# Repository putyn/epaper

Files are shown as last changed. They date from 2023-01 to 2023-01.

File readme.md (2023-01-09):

# epaper 
Adventure with epaper panel to create an epaper wifi connected photoframe.

Project is heavly based on [epdiy project](https://github.com/vroland/epdiy) but with a slightly different hardware, [epaper-breakout](epaper-breakout) is the first iteration of the project which will, hopefully, drive an ED060XC3 panel.

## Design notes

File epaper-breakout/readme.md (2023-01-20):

`Project status: Work in progress`

## ink-frame rev 0.1

Breakout board for [TPS65185](https://www.ti.com/lit/ds/symlink/tps65185.pdf) which supplies the 5 voltages needed to drive e-ink panels, [BQ24075](https://www.ti.com/lit/ds/symlink/bq24075.pdf) 
battery charger and FPC connector for e-ink panel, should fit ED060XC3 panel.

## pcb render
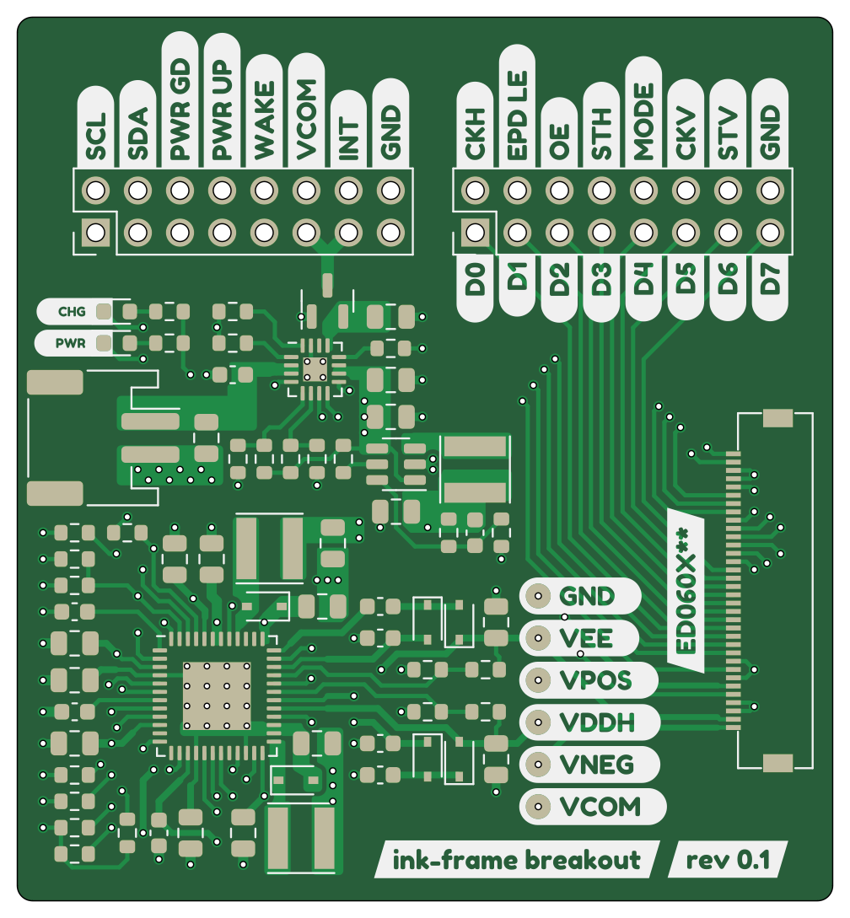
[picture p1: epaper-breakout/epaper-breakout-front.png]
ink-frame front


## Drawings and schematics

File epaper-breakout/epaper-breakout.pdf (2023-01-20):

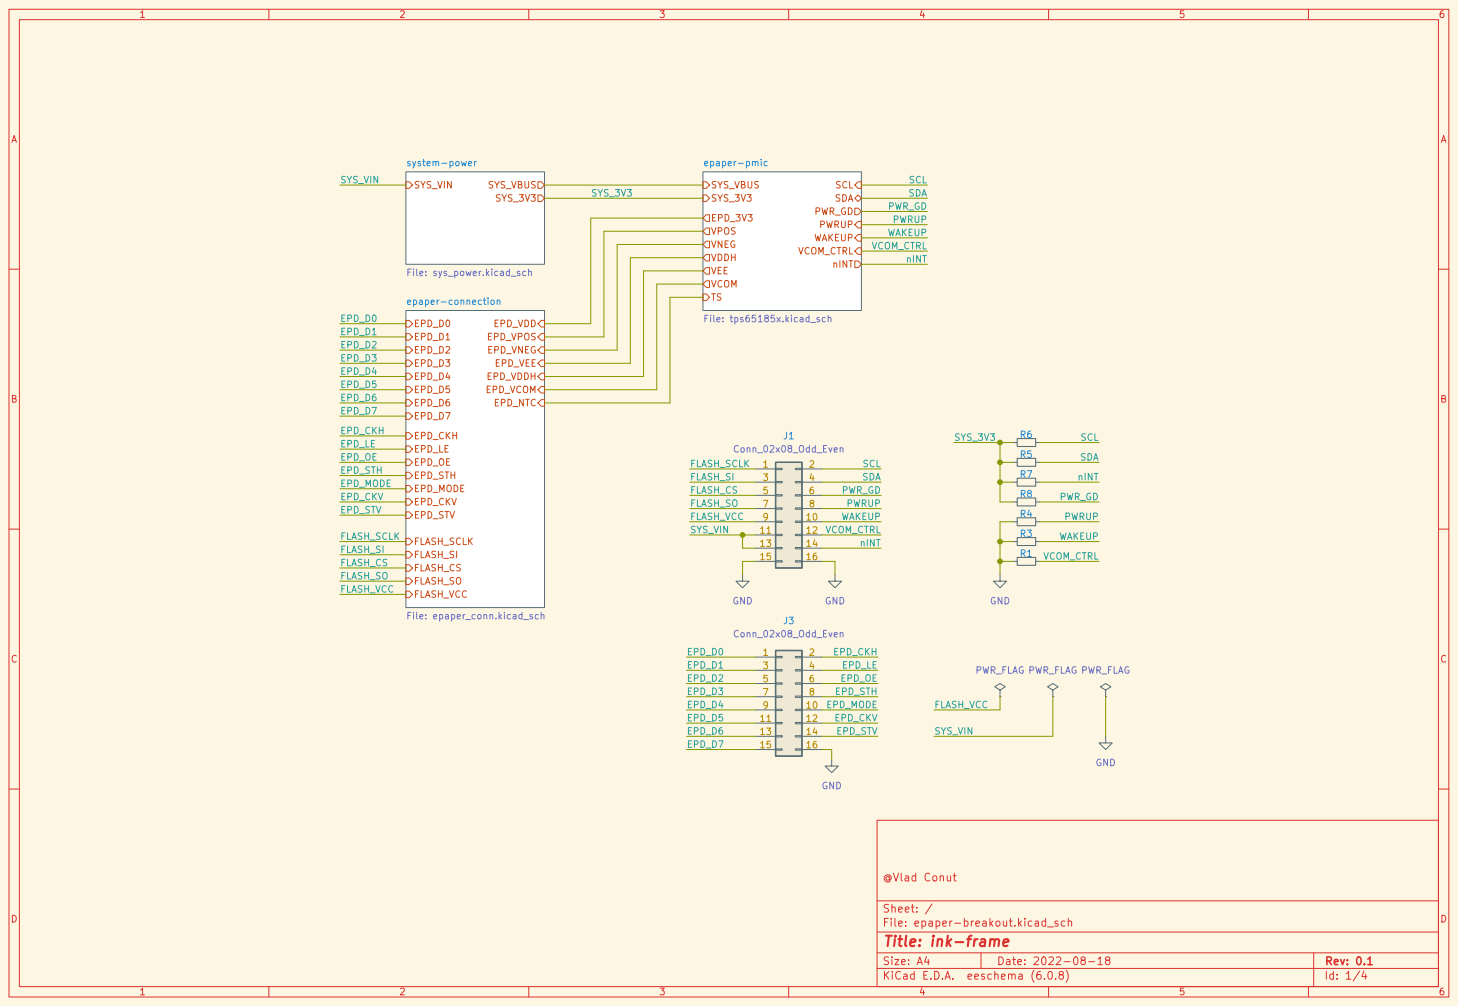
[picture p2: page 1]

File: epaper-breakout.kicad_sch Sheet: / @Vlad Conut

Id: 1/4 Title: ink-frame

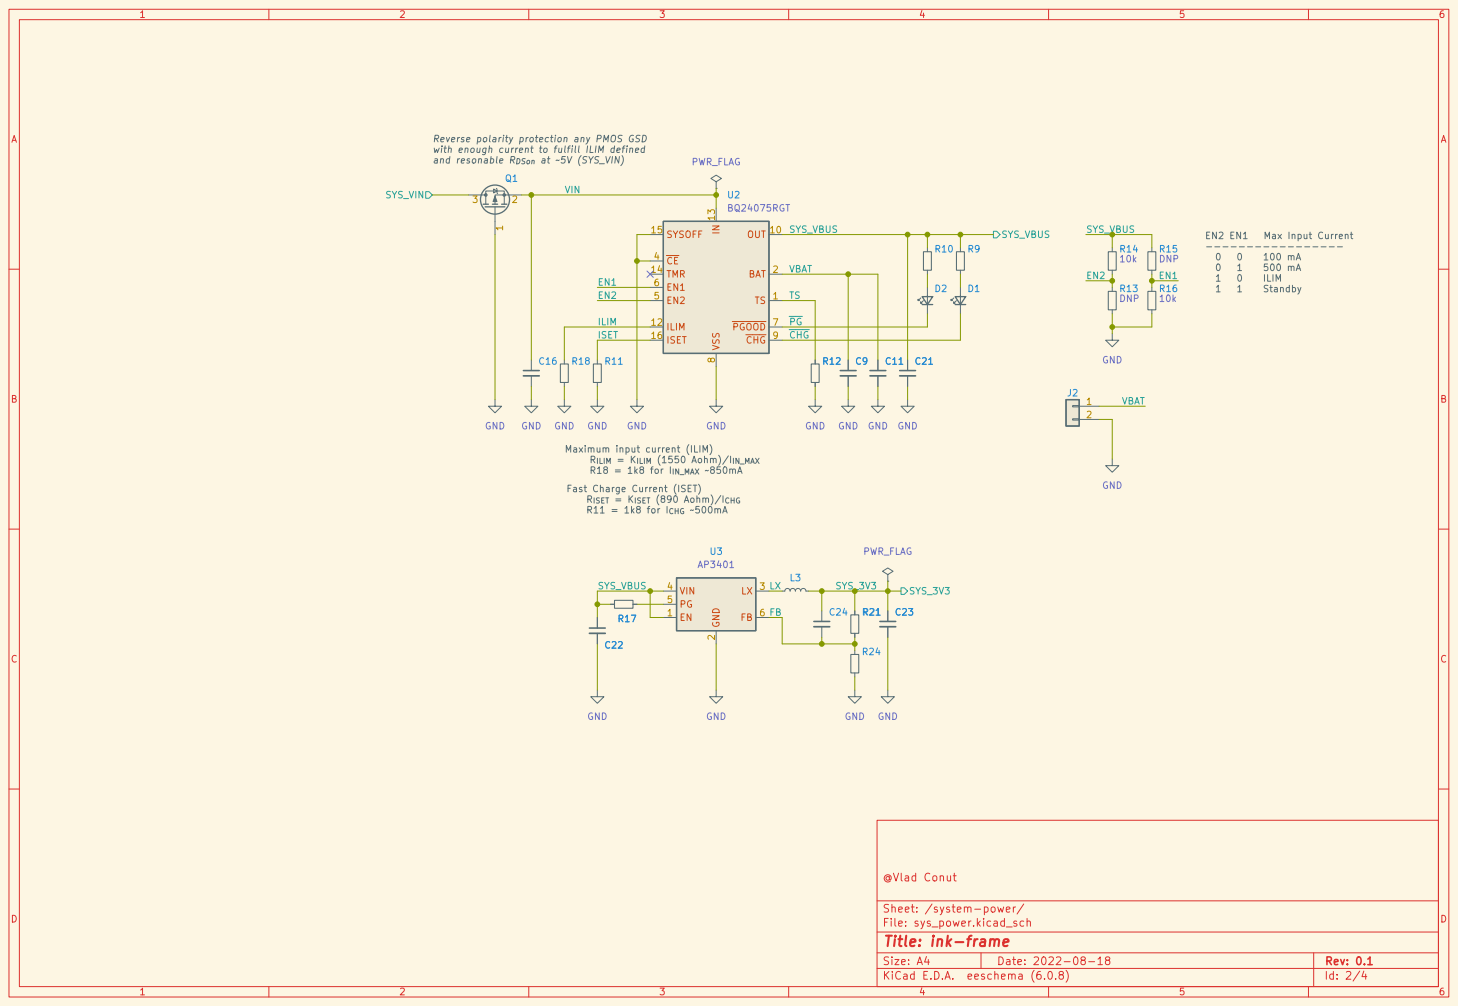
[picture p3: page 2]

Reverse polarity protection any PMOS GSD
with enough current to fulfill ILIM defined

Maximum input current (ILIM)
R_{ILIM} = K_{ILIM} (1550 Aohm)/I_{IN_MAX}
R18 = 1k8 for I_{IN_MAX} ~850mA
Fast Charge Current (ISET)
R_{ISET} = K_{ISET} (890 Aohm)/I_{CHG}
R11 = 1k8 for I_{CHG} ~500mA

Sheet: /system-power/
File: sys_power.kicad_sch
Id: 2/4 Title: ink-frame

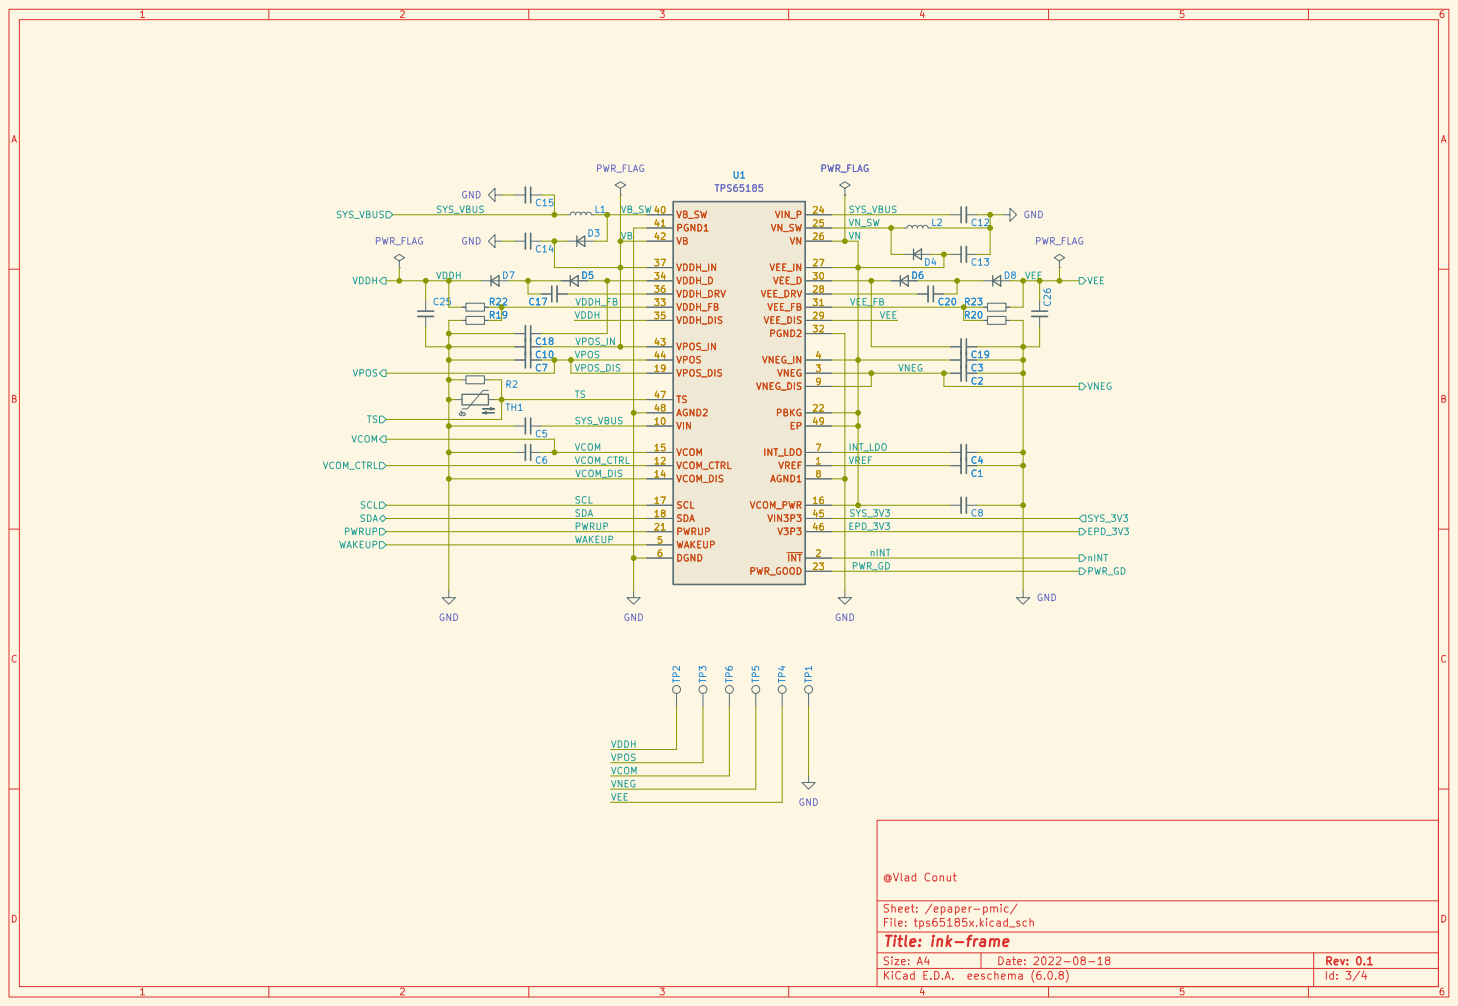
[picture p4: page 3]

VN_SW
VN

Sheet: /epaper-pmic/
File: tps65185x.kicad_sch
Id: 3/4 Title: ink-frame

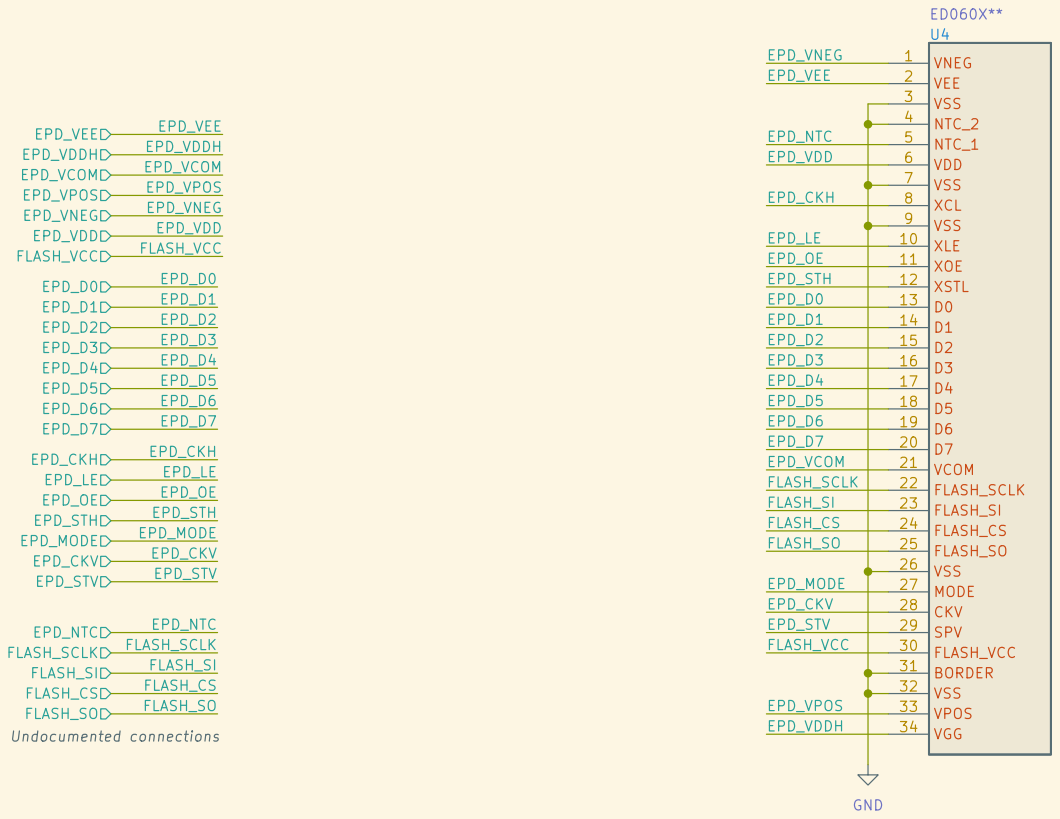
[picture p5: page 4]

Sheet: /epaper-connection/
File: epaper_conn.kicad_sch
Id: 4/4 Title: ink-frame

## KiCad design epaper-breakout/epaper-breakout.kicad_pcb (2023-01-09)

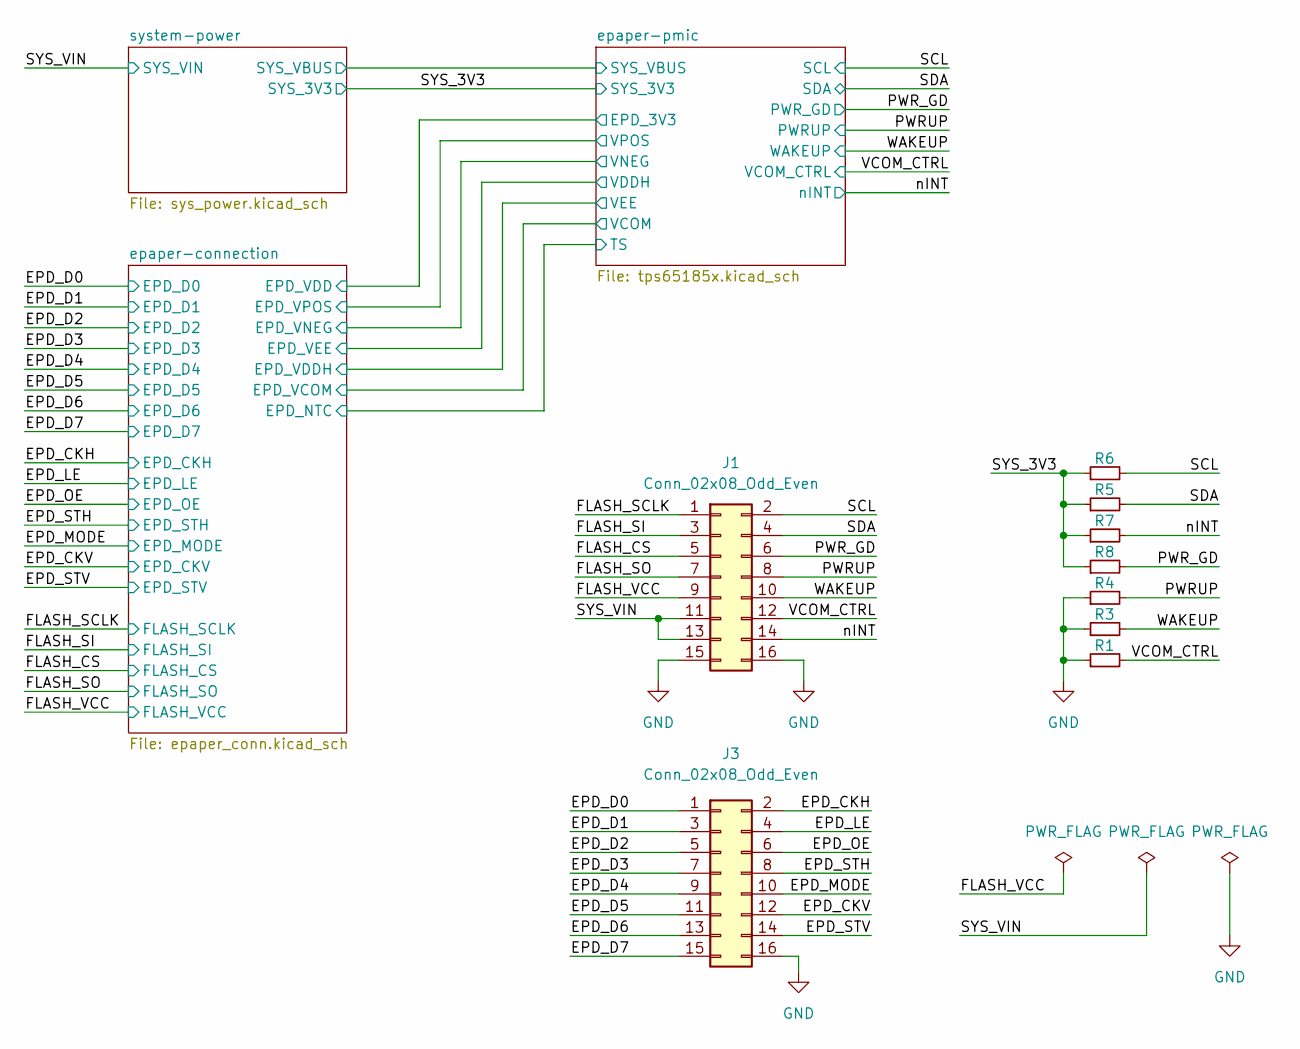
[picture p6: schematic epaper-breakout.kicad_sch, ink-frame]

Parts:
J1, J3: Conn_02x08_Odd_Even; PinHeader_2x08_P2.54mm_Vertical
R1, R3, R4, R7, R8: 100k; R_0603_1608Metric; LCSC C25803
R5, R6: 2k2; R_0603_1608Metric; LCSC C4190

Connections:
/EPD_CKH: J3.2; also elsewhere on the board
/EPD_CKV: J3.12; also elsewhere on the board
/EPD_D0: J3.1; also elsewhere on the board
/EPD_D1: J3.3; also elsewhere on the board
/EPD_D2: J3.5; also elsewhere on the board
/EPD_D3: J3.7; also elsewhere on the board
/EPD_D4: J3.9; also elsewhere on the board
/EPD_D5: J3.11; also elsewhere on the board
/EPD_D6: J3.13; also elsewhere on the board
/EPD_D7: J3.15; also elsewhere on the board
/EPD_LE: J3.4; also elsewhere on the board
/EPD_MODE: J3.10; also elsewhere on the board
/EPD_OE: J3.6; also elsewhere on the board
/EPD_STH: J3.8; also elsewhere on the board
/EPD_STV: J3.14; also elsewhere on the board
/FLASH_CS: J1.5; also elsewhere on the board
/FLASH_SCLK: J1.1; also elsewhere on the board
/FLASH_SI: J1.3; also elsewhere on the board
/FLASH_SO: J1.7; also elsewhere on the board
/FLASH_VCC: J1.9; also elsewhere on the board
/PWRUP: J1.8, R4.2; also elsewhere on the board
/PWR_GD: J1.6, R8.2; also elsewhere on the board
/SCL: J1.2, R6.2; also elsewhere on the board
/SDA: J1.4, R5.2; also elsewhere on the board
/SYS_3V3: R5.1, R6.1, R7.1, R8.1; also elsewhere on the board
/SYS_VIN: J1.11, J1.13; also elsewhere on the board
/VCOM_CTRL: J1.12, R1.2; also elsewhere on the board
/WAKEUP: J1.10, R3.2; also elsewhere on the board
/nINT: J1.14, R7.2; also elsewhere on the board
GND: J1.15, J1.16, J3.16, R1.1, R3.1, R4.1; also elsewhere on the board

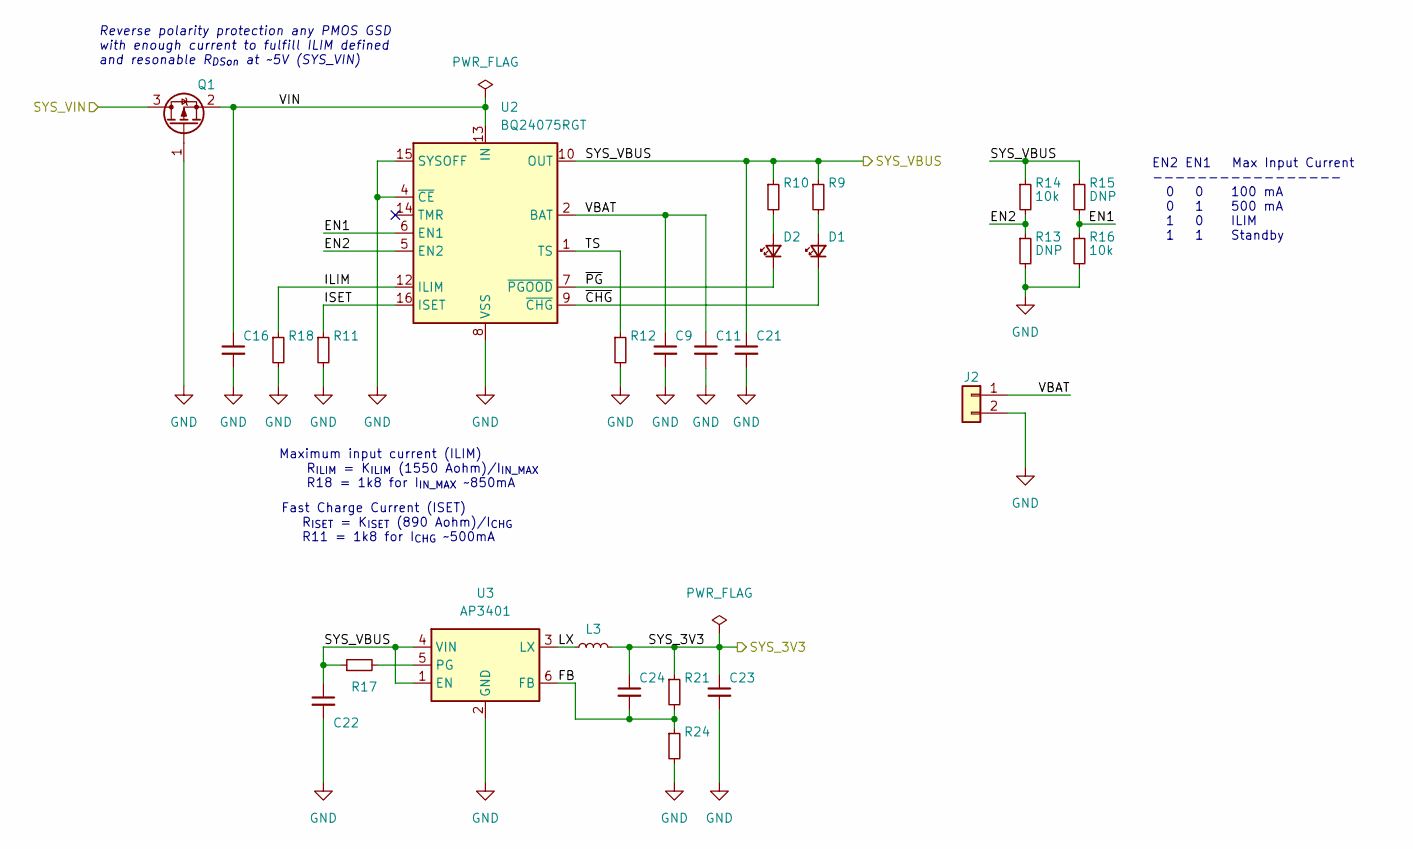
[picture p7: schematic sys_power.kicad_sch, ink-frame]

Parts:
C9, C16, C21, C22, C23: 10u;16V; C_0805_2012Metric; LCSC C17024
C11: 100n;25V; C_0603_1608Metric; LCSC C14663
C24: 22p; C_0603_1608Metric; LCSC C1653
D1, D2: RED; LED_0603_1608Metric; LCSC C965800
J2: Conn_01x02; JST_PH_S2B-PH-SM4-TB_1x02-1MP_P2.00mm_Horizontal; LCSC C47647
L3: 2u2; L_Taiyo-Yuden_NR-40xx; LCSC C98027
Q1: AO3401A; SOT-23; LCSC C15127
R9, R10: 2k2; R_0603_1608Metric; LCSC C4190
R11, R18: 1k8; R_0603_1608Metric; LCSC C4177
R12, R14, R16: 10k; R_0603_1608Metric; LCSC C25804
R13, R15: DNP; R_0603_1608Metric
R17, R24: 100k; R_0603_1608Metric; LCSC C25803
R21: 430k; R_0603_1608Metric; LCSC C25969
U2: BQ24075RGT; VQFN-16-1EP_3x3mm_P0.5mm_EP1.45x1.45mm_ThermalVias
U3: AP3401; TSOT-23-6

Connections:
/SYS_3V3: C23.1, C24.1, L3.2, R21.1; also elsewhere on the board
/SYS_VIN: Q1.3 (D); also elsewhere on the board
/epaper-pmic/SYS_VBUS: C21.1, C22.1, R9.1, R10.1, R14.1, R15.1, R17.1, U2.10 (OUT), U2.11 (OUT), U3.1 (EN), U3.4 (VIN); also elsewhere on the board
/system-power/EN1: R15.2, R16.1, U2.6 (EN1)
/system-power/EN2: R13.1, R14.2, U2.5 (EN2)
/system-power/FB: C24.2, R21.2, R24.1, U3.6 (FB)
/system-power/ILIM: R18.1, U2.12 (ILIM)
/system-power/ISET: R11.1, U2.16 (ISET)
/system-power/LX: L3.1, U3.3 (LX)
/system-power/TS: R12.1, U2.1 (TS)
/system-power/VBAT: C9.1, C11.1, J2.1, U2.2 (BAT), U2.3 (BAT)
/system-power/VIN: C16.1, Q1.2 (S), U2.13 (IN)
/system-power/~CHG: D1.1 (K), U2.9 (~CHG)
/system-power/~PG: D2.1 (K), U2.7 (~PGOOD)
GND: C9.2, C11.2, C16.2, C21.2, C22.2, C23.2, J2.2, Q1.1 (G), R11.2, R12.2, R13.2, R16.2, R18.2, R24.2, U2.4 (~CE), U2.8 (VSS), U2.15 (SYSOFF), U2.17 (VSS), U3.2 (GND); also elsewhere on the board
unnamed: D1.2 (A), R9.2
unnamed: D2.2 (A), R10.2
unnamed: R17.2, U3.5 (PG)

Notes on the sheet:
Maximum input current (ILIM) R_{ILIM} = K_{ILIM} (1550 Aohm)/I_{IN_MAX} R18 = 1k8 for I_{IN_MAX} ~850mA
Fast Charge Current (ISET) R_{ISET} = K_{ISET} (890 Aohm)/I_{CHG} R11 = 1k8 for I_{CHG} ~500mA
EN2 EN1 Max Input Current ----------------- 0 0 100 mA 0 1 500 mA 1 0 ILIM 1 1 Standby
Reverse polarity protection any PMOS GSD with enough current to fulfill ILIM defined and resonable R_{DSon} at ~5V (SYS_VIN)

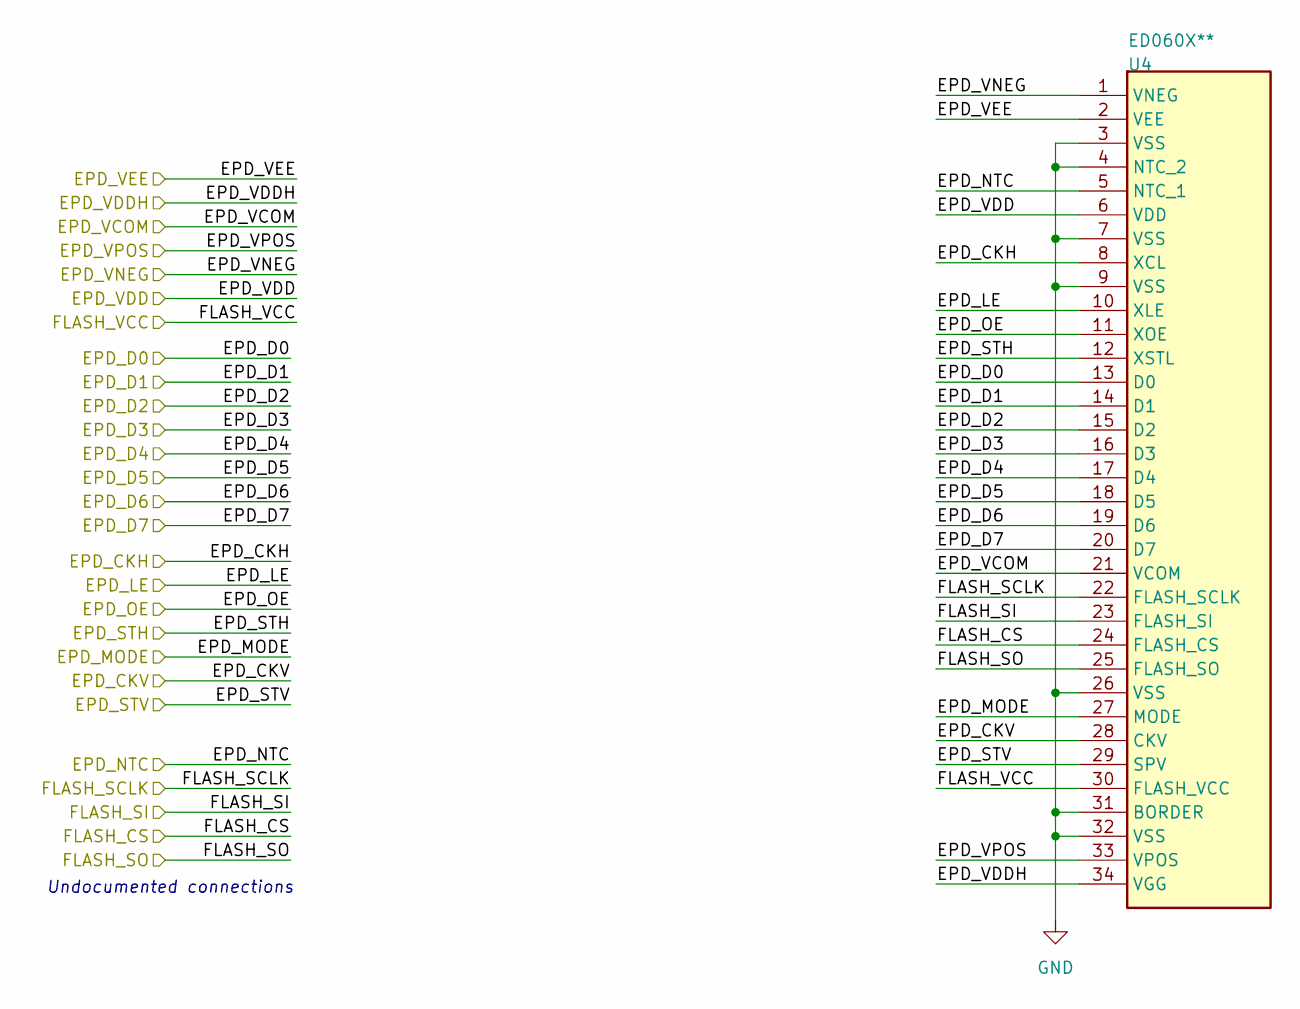
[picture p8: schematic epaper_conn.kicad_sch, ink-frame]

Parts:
U4: ED060X**; THD_THD0515-34CL-SN; LCSC C283154

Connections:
/EPD_CKH: U4.8 (XCL); also elsewhere on the board
/EPD_CKV: U4.28 (CKV); also elsewhere on the board
/EPD_D0: U4.13 (D0); also elsewhere on the board
/EPD_D1: U4.14 (D1); also elsewhere on the board
/EPD_D2: U4.15 (D2); also elsewhere on the board
/EPD_D3: U4.16 (D3); also elsewhere on the board
/EPD_D4: U4.17 (D4); also elsewhere on the board
/EPD_D5: U4.18 (D5); also elsewhere on the board
/EPD_D6: U4.19 (D6); also elsewhere on the board
/EPD_D7: U4.20 (D7); also elsewhere on the board
/EPD_LE: U4.10 (XLE); also elsewhere on the board
/EPD_MODE: U4.27 (MODE); also elsewhere on the board
/EPD_OE: U4.11 (XOE); also elsewhere on the board
/EPD_STH: U4.12 (XSTL); also elsewhere on the board
/EPD_STV: U4.29 (SPV); also elsewhere on the board
/FLASH_CS: U4.24 (FLASH_CS); also elsewhere on the board
/FLASH_SCLK: U4.22 (FLASH_SCLK); also elsewhere on the board
/FLASH_SI: U4.23 (FLASH_SI); also elsewhere on the board
/FLASH_SO: U4.25 (FLASH_SO); also elsewhere on the board
/FLASH_VCC: U4.30 (FLASH_VCC); also elsewhere on the board
/epaper-connection/EPD_NTC: U4.5 (NTC_1); also elsewhere on the board
/epaper-connection/EPD_VCOM: U4.21 (VCOM); also elsewhere on the board
/epaper-connection/EPD_VDD: U4.6 (VDD); also elsewhere on the board
/epaper-connection/EPD_VDDH: U4.34 (VGG); also elsewhere on the board
/epaper-connection/EPD_VEE: U4.2 (VEE); also elsewhere on the board
/epaper-connection/EPD_VNEG: U4.1 (VNEG); also elsewhere on the board
/epaper-connection/EPD_VPOS: U4.33 (VPOS); also elsewhere on the board
GND: U4.3 (VSS), U4.4 (NTC_2), U4.7 (VSS), U4.9 (VSS), U4.26 (VSS), U4.31 (BORDER), U4.32 (VSS); also elsewhere on the board

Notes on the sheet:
Undocumented connections

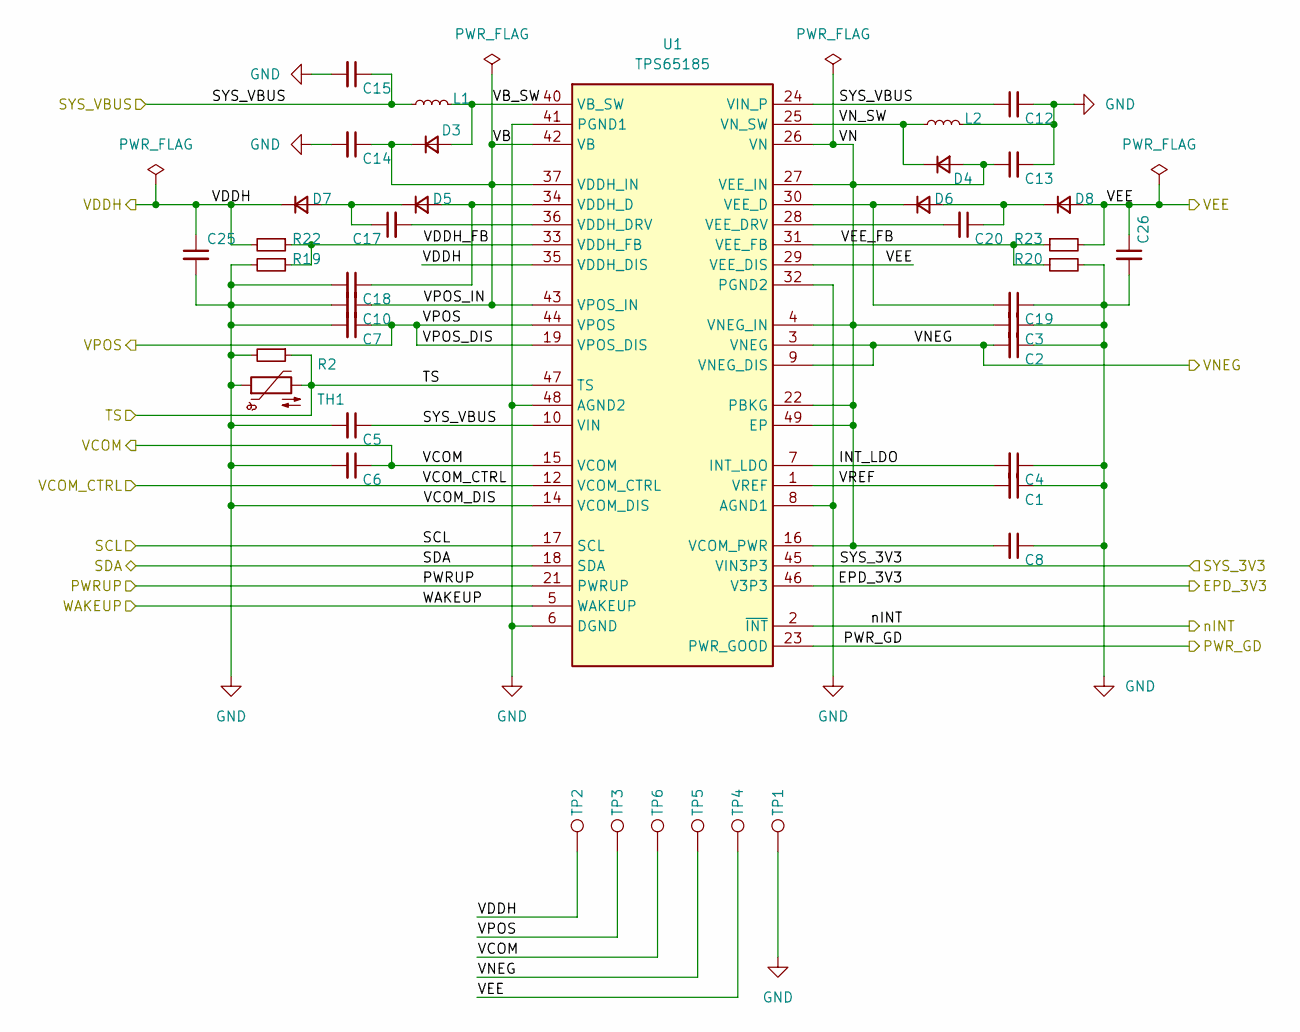
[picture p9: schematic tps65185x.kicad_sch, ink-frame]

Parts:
C1, C4, C6: 4u7;6V3; C_0603_1608Metric; LCSC C8032
C2, C3, C7, C8, C10, C13, C14: 4u7;25V; C_0805_2012Metric; LCSC C1779
C5, C12, C15: 10u;16V; C_0805_2012Metric; LCSC C17024
C17, C20: 10n;25V; C_0603_1608Metric; LCSC C1589
C18, C19: 100n;25V; C_0603_1608Metric; LCSC C14663
C25, C26: 4u7;50V; C_0805_2012Metric; LCSC C98192
D3, D4, D5, D6, D7, D8: 1N5819WS; D_SOD-323; LCSC C191023
L1: 2u2; L_Taiyo-Yuden_NR-40xx; LCSC C98027
L2: 4u7; L_Taiyo-Yuden_NR-40xx; LCSC C86081
R2: 43k; R_0603_1608Metric; LCSC C23172
R19: 47k5; R_0603_1608Metric; LCSC C25896
R20: 52k3; R_0603_1608Metric; LCSC C23198
R22, R23: 1M; R_0603_1608Metric; LCSC C22935
TH1: 10k; R_0603_1608Metric; LCSC C13564
TP1, TP2, TP3, TP4, TP5, TP6: TestPoint; TestPoint_Pad_D1.5mm
U1: TPS65185; VQFN-48-1EP_7x7mm_P0.5mm_EP4.1x4.1mm_ThermalVias

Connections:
/PWRUP: U1.21 (PWRUP); also elsewhere on the board
/PWR_GD: U1.23 (PWR_GOOD); also elsewhere on the board
/SCL: U1.17 (SCL); also elsewhere on the board
/SDA: U1.18 (SDA); also elsewhere on the board
/SYS_3V3: U1.45 (VIN3P3); also elsewhere on the board
/VCOM_CTRL: U1.12 (VCOM_CTRL); also elsewhere on the board
/WAKEUP: U1.5 (WAKEUP); also elsewhere on the board
/epaper-connection/EPD_NTC: R2.1, TH1.2, U1.47 (TS); also elsewhere on the board
/epaper-connection/EPD_VCOM: C6.1, TP6.1, U1.15 (VCOM); also elsewhere on the board
/epaper-connection/EPD_VDD: U1.46 (V3P3); also elsewhere on the board
/epaper-connection/EPD_VDDH: C26.1, D8.2 (A), R23.2, TP4.1, U1.29 (VEE_DIS); also elsewhere on the board
/epaper-connection/EPD_VEE: C25.1, D7.1 (K), R22.2, TP2.1, U1.35 (VDDH_DIS); also elsewhere on the board
/epaper-connection/EPD_VNEG: C2.2, TP5.1, U1.3 (VNEG), U1.9 (VNEG_DIS); also elsewhere on the board
/epaper-connection/EPD_VPOS: C7.1, TP3.1, U1.19 (VPOS_DIS), U1.44 (VPOS); also elsewhere on the board
/epaper-pmic/INT_LDO: C4.2, U1.7 (INT_LDO)
/epaper-pmic/SYS_VBUS: C5.1, C12.1, C15.1, L1.1, U1.10 (VIN), U1.24 (VIN_P); also elsewhere on the board
/epaper-pmic/VDDH_FB: R19.1, R22.1, U1.33 (VDDH_FB)
/epaper-pmic/VEE_FB: R20.1, R23.1, U1.31 (VEE_FB)
/epaper-pmic/VN: C3.2, C8.2, C13.1, D4.2 (A), U1.4 (VNEG_IN), U1.16 (VCOM_PWR), U1.22 (PBKG), U1.26 (VN), U1.27 (VEE_IN), U1.49 (EP)
/epaper-pmic/VN_SW: D4.1 (K), L2.2, U1.25 (VN_SW)
/epaper-pmic/VREF: C1.2, U1.1 (VREF)
/nINT: U1.2 (~INT); also elsewhere on the board
GND: C1.1, C2.1, C3.1, C4.1, C5.2, C6.2, C7.2, C8.1, C10.2, C12.2, C13.2, C14.2, C15.2, C18.2, C19.1, C25.2, C26.2, L2.1, R2.2, R19.2, R20.2, TH1.1, TP1.1, U1.6 (DGND), U1.8 (AGND1), U1.14 (VCOM_DIS), U1.32 (PGND2), U1.41 (PGND1), U1.48 (AGND2); also elsewhere on the board
unnamed: C17.1, D5.1 (K), D7.2 (A)
unnamed: C17.2, U1.36 (VDDH_DRV)
unnamed: C18.1, D5.2 (A), U1.34 (VDDH_D)
unnamed 58: C19.2, D6.1 (K), U1.30 (VEE_D); also elsewhere on the board
unnamed 59: C20.1, D6.2 (A), D8.1 (K); also elsewhere on the board
unnamed: C20.2, U1.28 (VEE_DRV)

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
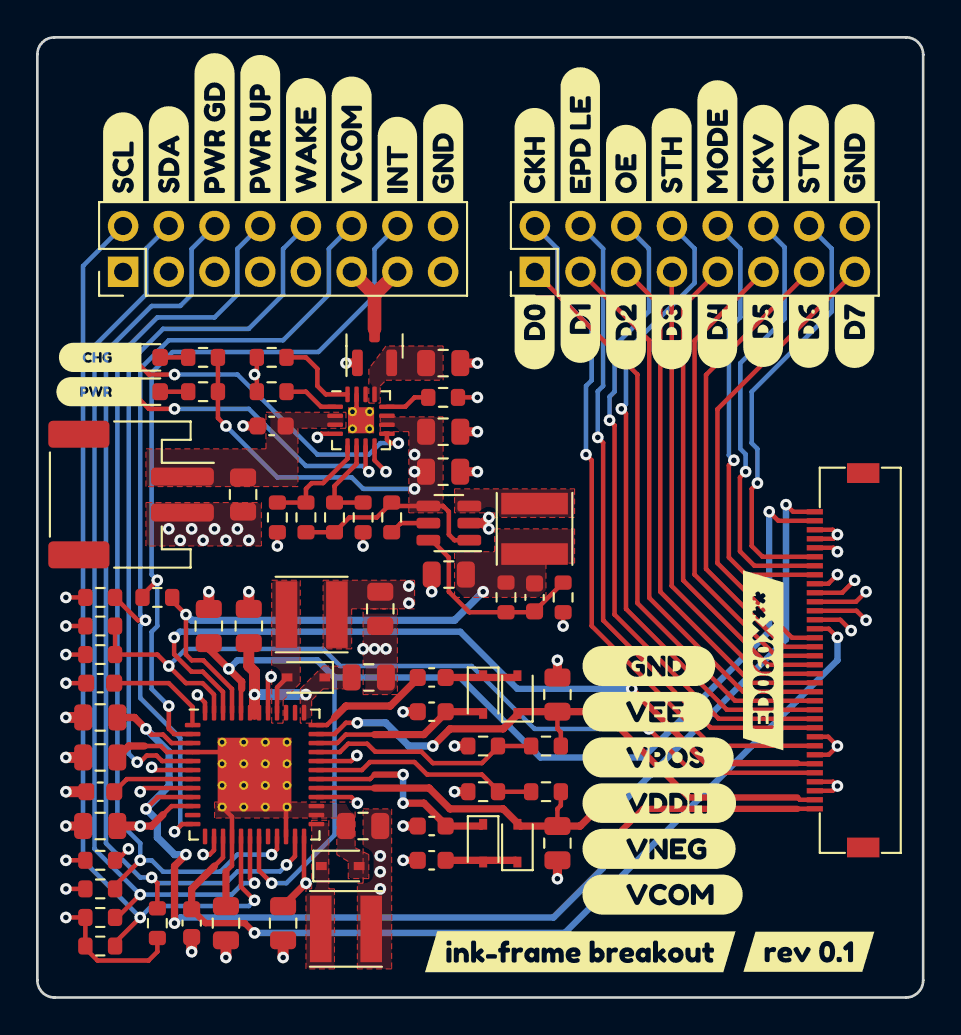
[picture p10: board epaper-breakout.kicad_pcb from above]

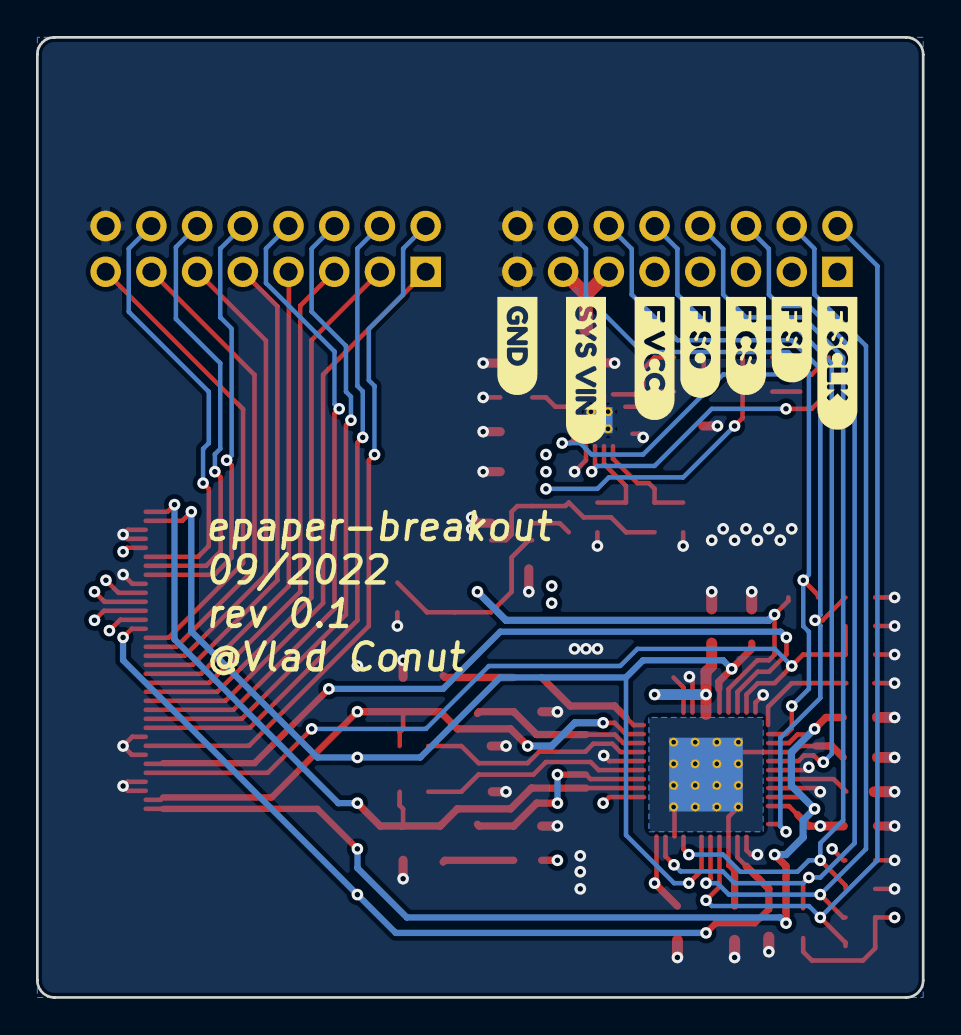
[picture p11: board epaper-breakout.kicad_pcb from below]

Board: 4 copper layers, 49.2 x 53.3 mm, 118 parts (7 on the bottom side), 66 nets.

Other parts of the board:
kibuzzard-1: G***; kibuzzard-63060977
kibuzzard-2: G***; kibuzzard-6306091E
kibuzzard-3: G***; kibuzzard-6304CD62
kibuzzard-4: G***; kibuzzard-6304CD58
kibuzzard-5: G***; kibuzzard-6304CD7C
kibuzzard-6: G***; kibuzzard-6304CD98
kibuzzard-7: G***; kibuzzard-6304CDA2
kibuzzard-8: G***; kibuzzard-6304CE57
kibuzzard-9: G***; kibuzzard-6304CE9C
kibuzzard-10, kibuzzard-34, kibuzzard-34#2: G***; kibuzzard-6304CEA6
kibuzzard-11: G***; kibuzzard-6304CAAC
kibuzzard-12: G***; kibuzzard-6304CBD9
kibuzzard-13: G***; kibuzzard-6304CA26
kibuzzard-14: G***; kibuzzard-6304CBCE
kibuzzard-15: G***; kibuzzard-6307DF07
kibuzzard-16: G***; kibuzzard-6304CA4F
kibuzzard-17: G***; kibuzzard-6304CBC7
kibuzzard-18: G***; kibuzzard-6305306A
kibuzzard-19: G***; kibuzzard-63052A6A
kibuzzard-20: G***; kibuzzard-63052A59
kibuzzard-21: G***; kibuzzard-63052A0A
kibuzzard-22: G***; kibuzzard-630529E3
kibuzzard-23: G***; kibuzzard-63052909
kibuzzard-24: G***; kibuzzard-6304CA73
kibuzzard-25: G***; kibuzzard-6304CBC0
kibuzzard-26: G***; kibuzzard-6304CA80
kibuzzard-27: G***; kibuzzard-6304CBB8
kibuzzard-28: G***; kibuzzard-6304CA8E
kibuzzard-29: G***; kibuzzard-6304CBAE
kibuzzard-30: G***; kibuzzard-6304C9DD
kibuzzard-31: G***; kibuzzard-6304CA9B
kibuzzard-32: G***; kibuzzard-6304CBA2
kibuzzard-33: G***; kibuzzard-63108B63
kibuzzard-35: G***; kibuzzard-6304CB97
kibuzzard-631C7B6B: G***; kibuzzard-631C7B6B
kibuzzard-631C7BA9: G***; kibuzzard-631C7BA9
kibuzzard-631C7BBA: G***; kibuzzard-631C7BBA
kibuzzard-631C7BCA: G***; kibuzzard-631C7BCA
kibuzzard-631C7BDB: G***; kibuzzard-631C7BDB
kibuzzard-631C7BE9: G***; kibuzzard-631C7BE9
locked: B5819WS; D_SOD-323
locked#2: B5819WS; D_SOD-323

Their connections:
/epaper-connection/EPD_VDDH: locked#2.2 (A); also elsewhere on the board
unnamed 58: locked.1 (K); also elsewhere on the board
unnamed 59: locked.2 (A), locked#2.1 (K); also elsewhere on the board

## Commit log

2023-01-09 various display specs found around the internet and first hardware iteration
    [epaper-breakout.kicad_pcb, epaper-breakout.kicad_sch, epaper_conn.kicad_sch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]
2023-01-20 schematic and PCB front side render
